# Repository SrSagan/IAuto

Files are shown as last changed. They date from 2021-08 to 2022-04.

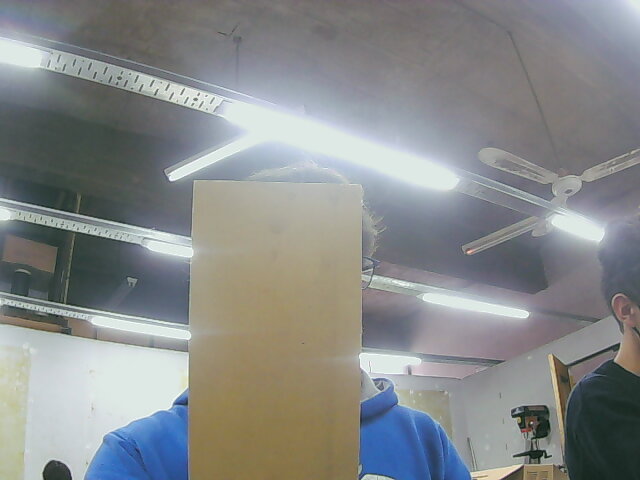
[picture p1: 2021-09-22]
camera/foto1.jpg

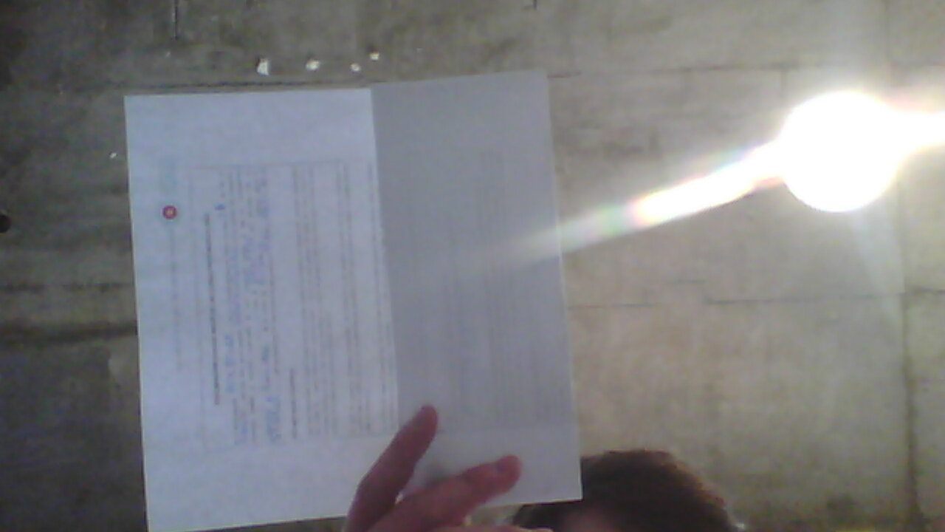
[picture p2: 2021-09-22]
camera/cuadrado.jpg

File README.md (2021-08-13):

# IAuto

IAuto is a little car that's controlled by an artificial intelligence, the brain of the operations is a Raspberry pi 3 that's controlling 2 DC motors and has a camera connected to it.

# Objectives

This project is merely for education, not only learn how to code advanced algorithms but also to use as an example for other poeple who might be trying to learn something similar.

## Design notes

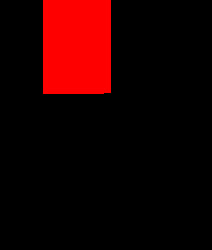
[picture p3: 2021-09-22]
camera/square.jpg

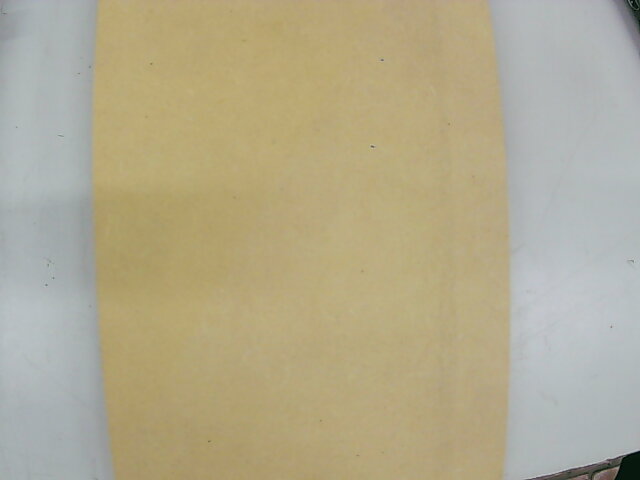
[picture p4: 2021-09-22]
camera/foto2.jpg

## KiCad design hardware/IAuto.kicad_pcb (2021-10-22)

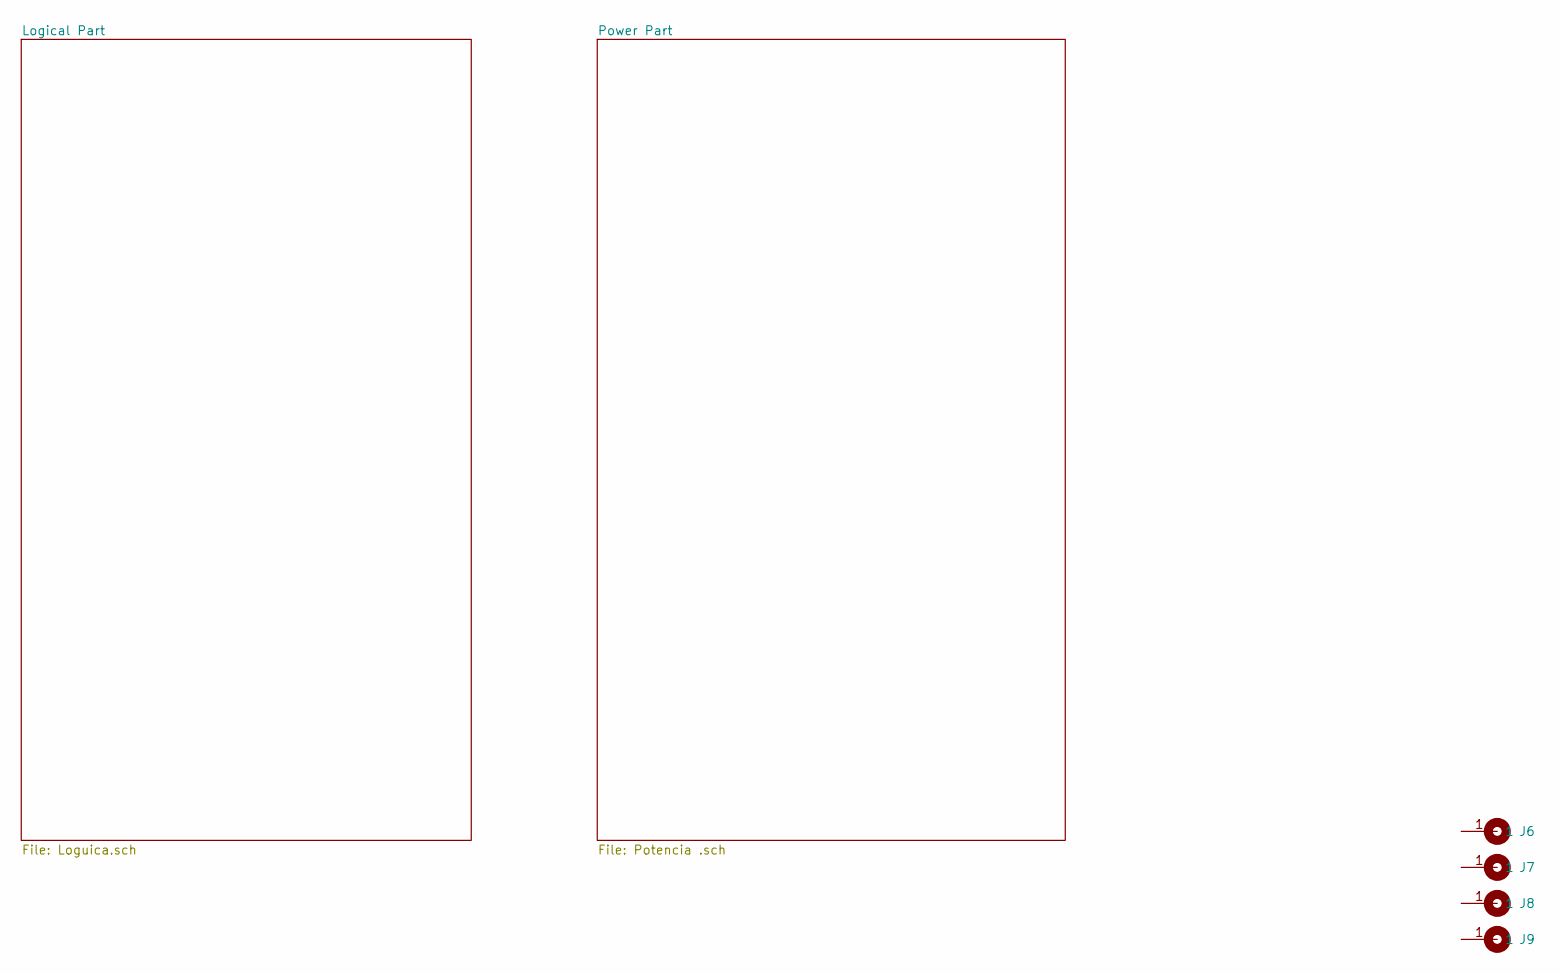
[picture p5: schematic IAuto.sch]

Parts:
J6, J7, J8, J9: Cable_PAD; Separador_M3_10mm

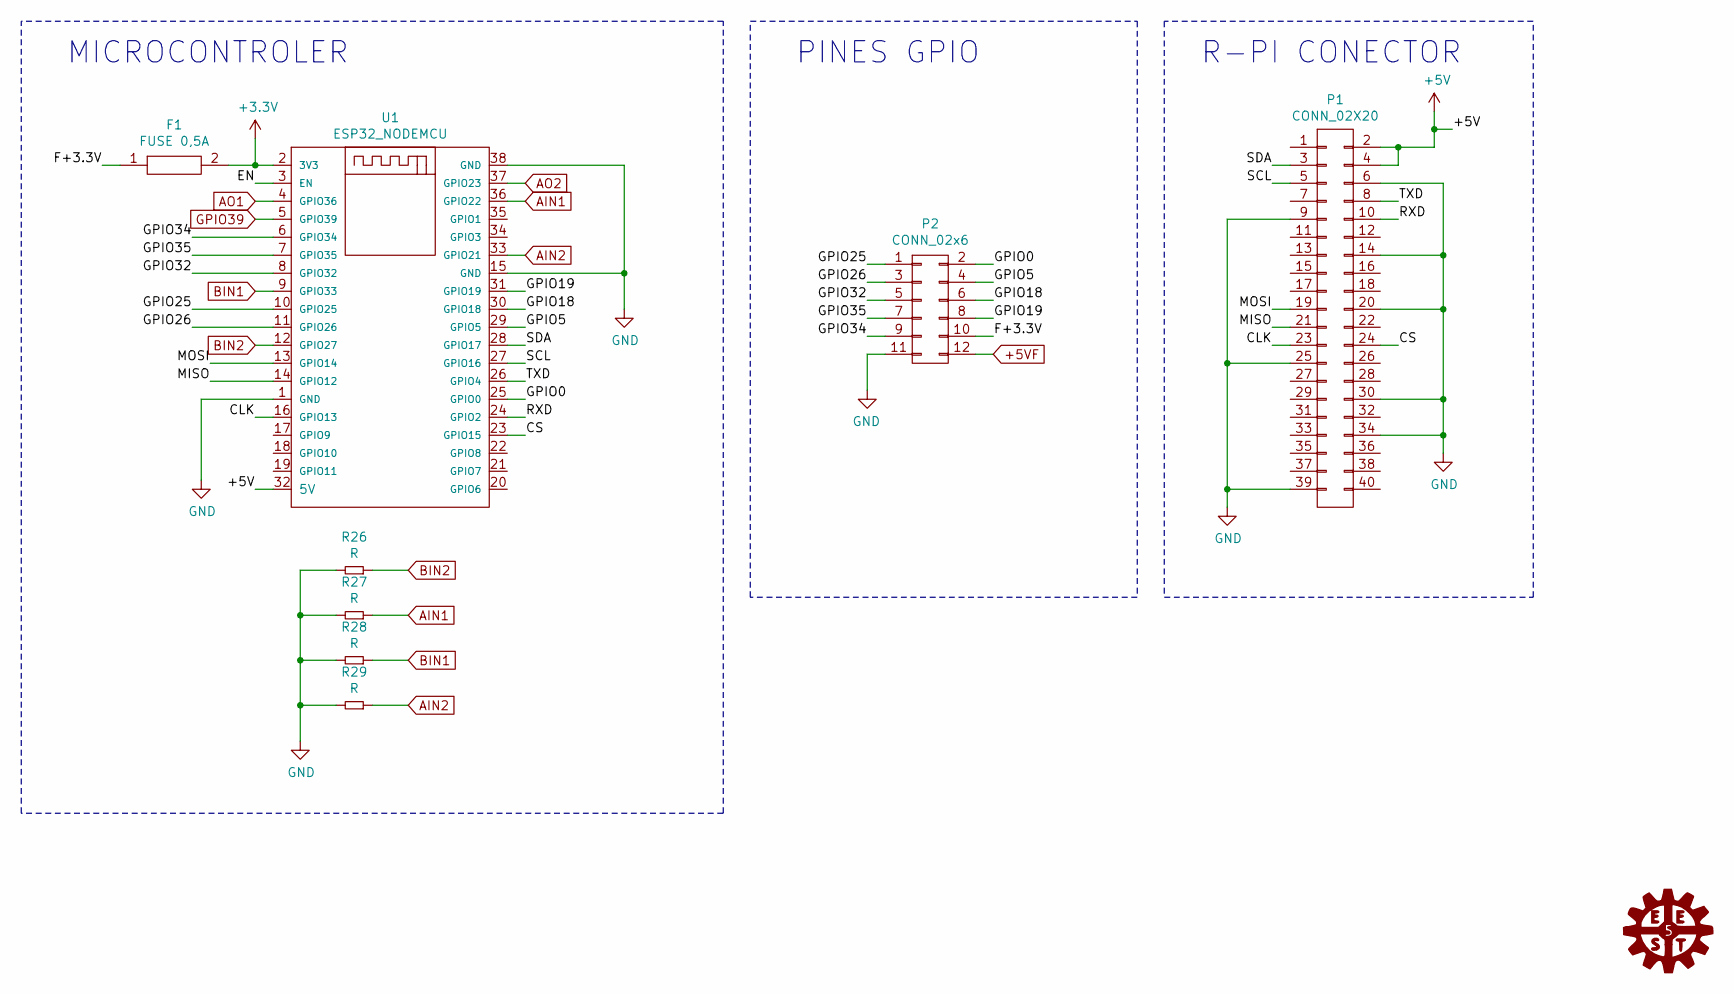
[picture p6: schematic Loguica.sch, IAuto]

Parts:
F1: FUSE 0,5A; R_1206
P1: CONN_02X20; Pin_Header_Straight_2x20
P2: CONN_02x6; Pin_strip_2x6
R26, R27, R28, R29: R; R_0805
U1: ESP32_NODEMCU; NodeMCU-ESP32

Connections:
+3V3: F1.2, U1.2 (3V3); also elsewhere on the board
+5V: P1.2, P1.4, U1.32 (5V); also elsewhere on the board
+5VF: P2.12; also elsewhere on the board
/Logical Part/CLK: P1.23, U1.16 (GPIO13)
/Logical Part/CS: P1.24, U1.23 (GPIO15)
/Logical Part/F+3.3V: F1.1, P2.10
/Logical Part/GPIO0: P2.2, U1.25 (GPIO0)
/Logical Part/GPIO5: P2.4, U1.29 (GPIO5)
/Logical Part/GPIO18: P2.6, U1.30 (GPIO18)
/Logical Part/GPIO19: P2.8, U1.31 (GPIO19)
/Logical Part/GPIO25: P2.1, U1.10 (GPIO25)
/Logical Part/GPIO26: P2.3, U1.11 (GPIO26)
/Logical Part/GPIO32: P2.5, U1.8 (GPIO32)
/Logical Part/GPIO34: P2.9, U1.6 (GPIO34)
/Logical Part/GPIO35: P2.7, U1.7 (GPIO35)
/Logical Part/MISO: P1.21, U1.14 (GPIO12)
/Logical Part/MOSI: P1.19, U1.13 (GPIO14)
/Logical Part/RXD: P1.10, U1.24 (GPIO2)
/Logical Part/SCL: P1.5, U1.27 (GPIO16)
/Logical Part/SDA: P1.3, U1.28 (GPIO17)
/Logical Part/TXD: P1.8, U1.26 (GPIO4)
AIN1: R27.1, U1.36 (GPIO22); also elsewhere on the board
AIN2: R29.1, U1.33 (GPIO21); also elsewhere on the board
AO1: U1.4 (GPIO36); also elsewhere on the board
AO2: U1.37 (GPIO23); also elsewhere on the board
BIN1: R28.1, U1.9 (GPIO33); also elsewhere on the board
BIN2: R26.1, U1.12 (GPIO27); also elsewhere on the board
GND: P1.6, P1.9, P1.14, P1.20, P1.25, P1.30, P1.34, P1.39, P2.11, R26.2, R27.2, R28.2, R29.2, U1.1 (GND), U1.15 (GND), U1.38 (GND); also elsewhere on the board
GPIO39: U1.5 (GPIO39); also elsewhere on the board

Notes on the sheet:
MICROCONTROLER
R-PI CONECTOR
PINES GPIO

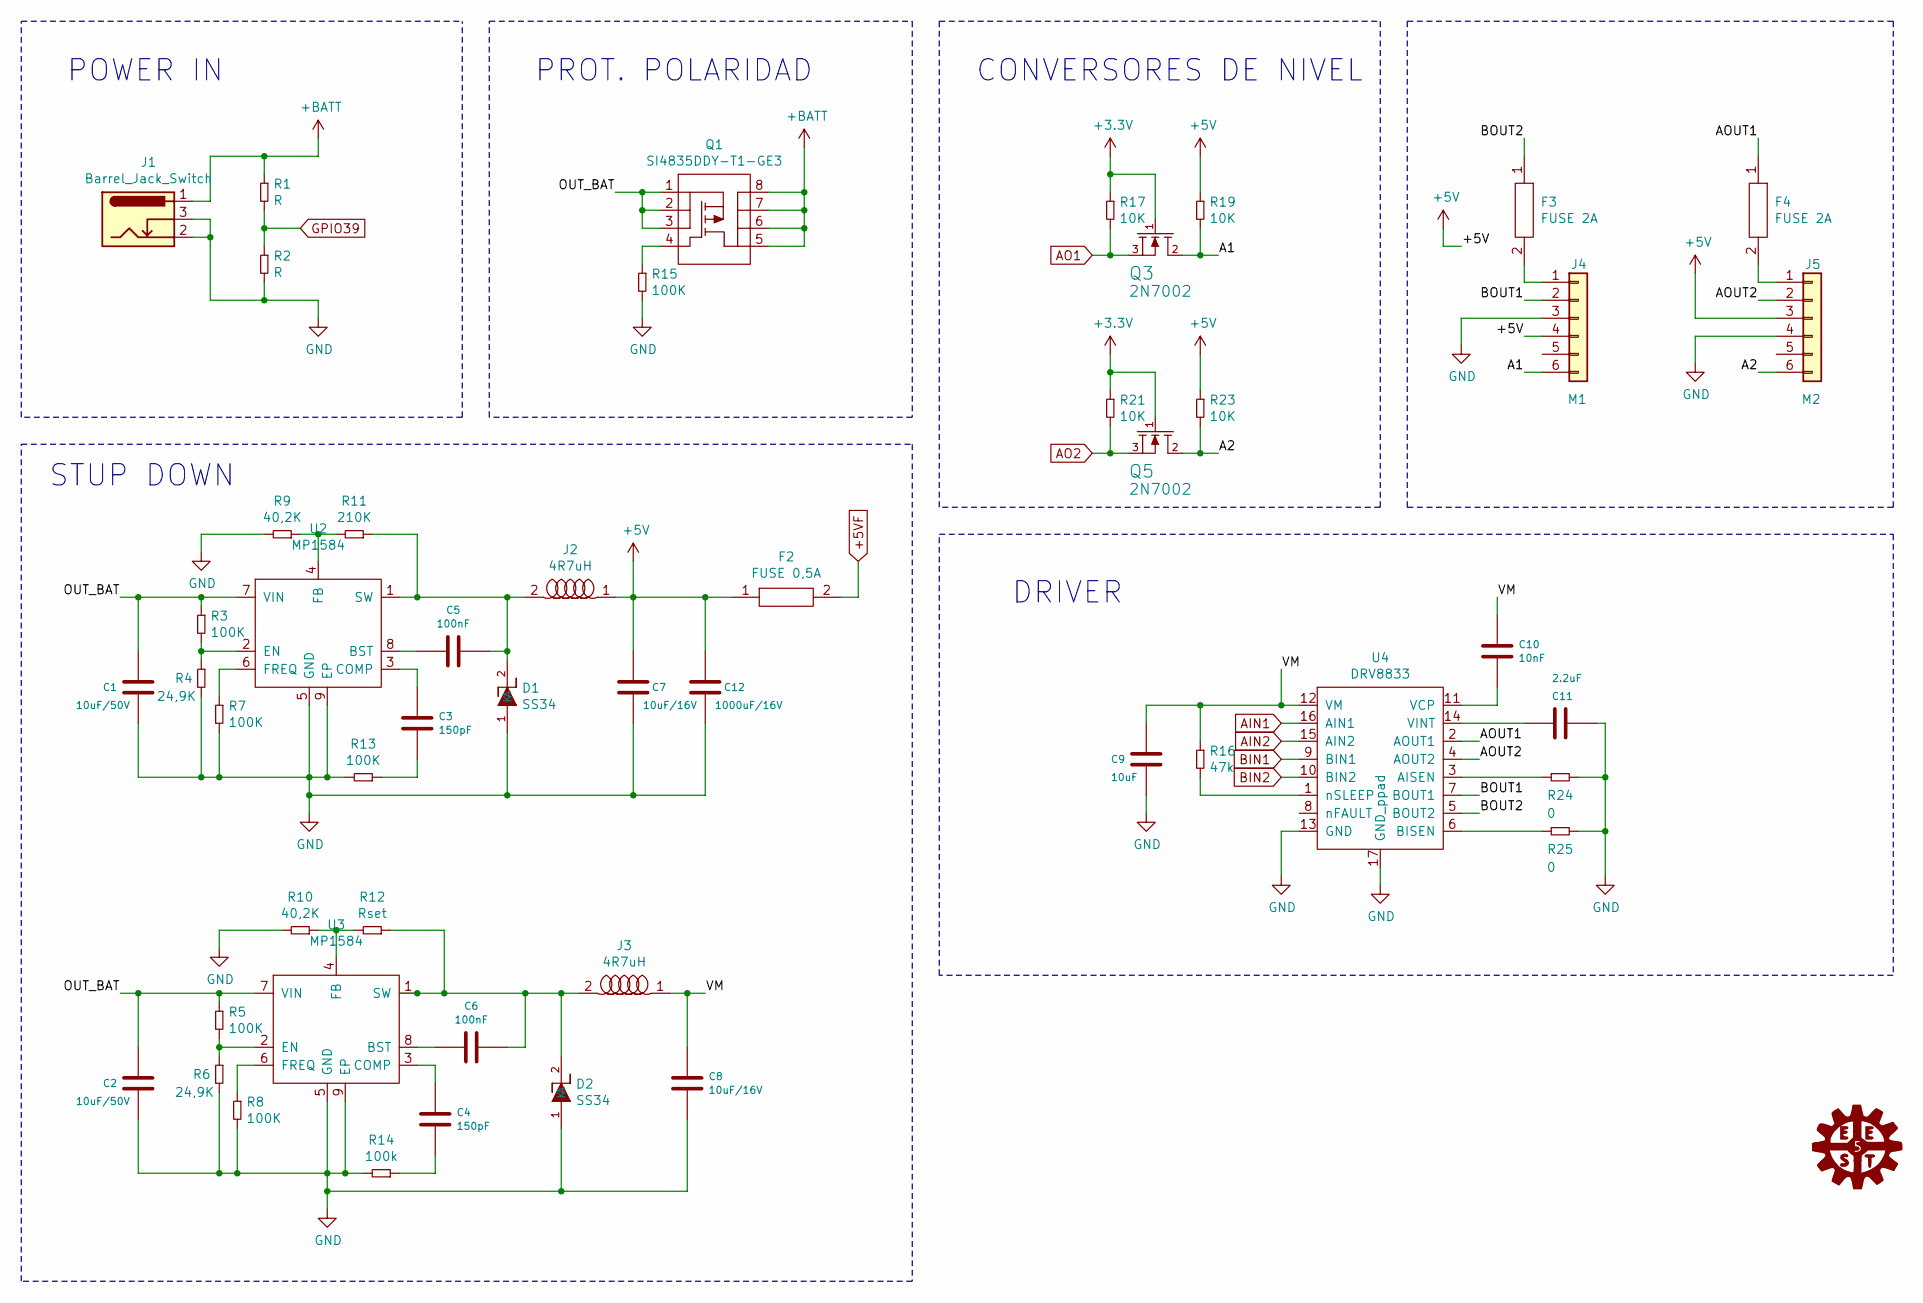
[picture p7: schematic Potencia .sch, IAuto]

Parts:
C1, C2: 10uF/50V; C_1206
C3, C4: 150pF; C_0805
C5, C6: 100nF; C_0805
C7, C8: 10uF/16V; C_1206
C9: 10uF; C_1206
C10: 10nF; C_0805
C11: 2.2uF; C_0805
C12: 1000uF/16V; CAP_ELEC_8x11.5mm
D1, D2: SS34; DO-214AB
F2: FUSE 0,5A; R_1206
F3, F4: FUSE 2A; FUSC5141X200N
J1: Barrel_Jack_Switch; Jack_hembra_DC_barrel
J2, J3: 4R7uH; SRP65404R7M
J4: M1; Conector_jst_6_pins_2mm
J5: M2; Conector_jst_6_pins_2mm
Q1: SI4835DDY-T1-GE3; SSOP-8
Q3, Q5: 2N7002; SOT23
R1, R2: R; R_0805
R3, R5, R7, R8, R13, R15: 100K; R_0805
R4, R6: 24,9K; R_0805
R9, R10: 40,2K; R_0805
R11: 210K; R_0805
R12: Rset; R_0805
R14: 100k; R_0805
R16: 47k; R_0805
R17, R19, R21, R23: 10K; R_0805
R24, R25: 0; R_0805
U2, U3: MP1584; SOIC8E
U4: DRV8833; HTSSOPP

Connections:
+3V3: Q3.1 (G), Q5.1 (G), R17.1, R21.1; also elsewhere on the board
+5V: C7.2, C12.1, F2.1, J2.1, J4.4, J5.3, R19.1, R23.1; also elsewhere on the board
+5VF: F2.2; also elsewhere on the board
+BATT: J1.1, Q1.5, Q1.6, Q1.7, Q1.8, R1.1
/Power Part/A1: J4.6, Q3.2 (D), R19.2
/Power Part/A2: J5.6, Q5.2 (D), R23.2
/Power Part/AOUT1: F4.1, U4.2 (AOUT1)
/Power Part/AOUT2: J5.2, U4.4 (AOUT2)
/Power Part/BOUT1: J4.2, U4.7 (BOUT1)
/Power Part/BOUT2: F3.1, U4.5 (BOUT2)
/Power Part/OUT_BAT: C1.2, C2.2, Q1.1, Q1.2, Q1.3, R3.1, R5.1, U2.7 (VIN), U3.7 (VIN)
/Power Part/VM: C8.2, C9.1, C10.1, J3.1, R16.1, U4.12 (VM)
AIN1: U4.16 (AIN1); also elsewhere on the board
AIN2: U4.15 (AIN2); also elsewhere on the board
AO1: Q3.3 (S), R17.2; also elsewhere on the board
AO2: Q5.3 (S), R21.2; also elsewhere on the board
BIN1: U4.9 (BIN1); also elsewhere on the board
BIN2: U4.10 (BIN2); also elsewhere on the board
GND: C1.1, C2.1, C7.1, C8.1, C9.2, C11.1, C12.2, D1.1 (A), D2.1 (A), J1.2, J1.3, J4.3, J5.4, R2.2, R4.2, R6.2, R7.2, R8.2, R9.2, R10.2, R13.2, R14.2, R15.2, R24.2, R25.2, U2.5 (GND), U2.9 (EP), U3.5 (GND), U3.9 (EP), U4.13 (GND), U4.17 (GND_ppad); also elsewhere on the board
GPIO39: R1.2, R2.1; also elsewhere on the board
unnamed: C3.1, R13.1
unnamed: C3.2, U2.3 (COMP)
unnamed: C4.1, R14.1
unnamed: C4.2, U3.3 (COMP)
unnamed: C5.1, U2.8 (BST)
unnamed: C5.2, D1.2 (K), J2.2, R11.1, U2.1 (SW)
unnamed: C6.1, U3.8 (BST)
unnamed: C6.2, D2.2 (K), J3.2, R12.1, U3.1 (SW)
unnamed: C10.2, U4.11 (VCP)
unnamed: C11.2, U4.14 (VINT)
unnamed: F3.2, J4.1
unnamed: F4.2, J5.1
unnamed: Q1.4, R15.1
unnamed: R3.2, R4.1, U2.2 (EN)
unnamed: R5.2, R6.1, U3.2 (EN)
unnamed: R7.1, U2.6 (FREQ)
unnamed: R8.1, U3.6 (FREQ)
unnamed: R10.1, R12.2, U3.4 (FB)
unnamed: R9.1, R11.2, U2.4 (FB)
unnamed: R16.2, U4.1 (nSLEEP)
unnamed: R24.1, U4.3 (AISEN)
unnamed: R25.1, U4.6 (BISEN)

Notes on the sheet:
POWER IN
CONVERSORES DE NIVEL
PROT. POLARIDAD
STUP DOWN
DRIVER

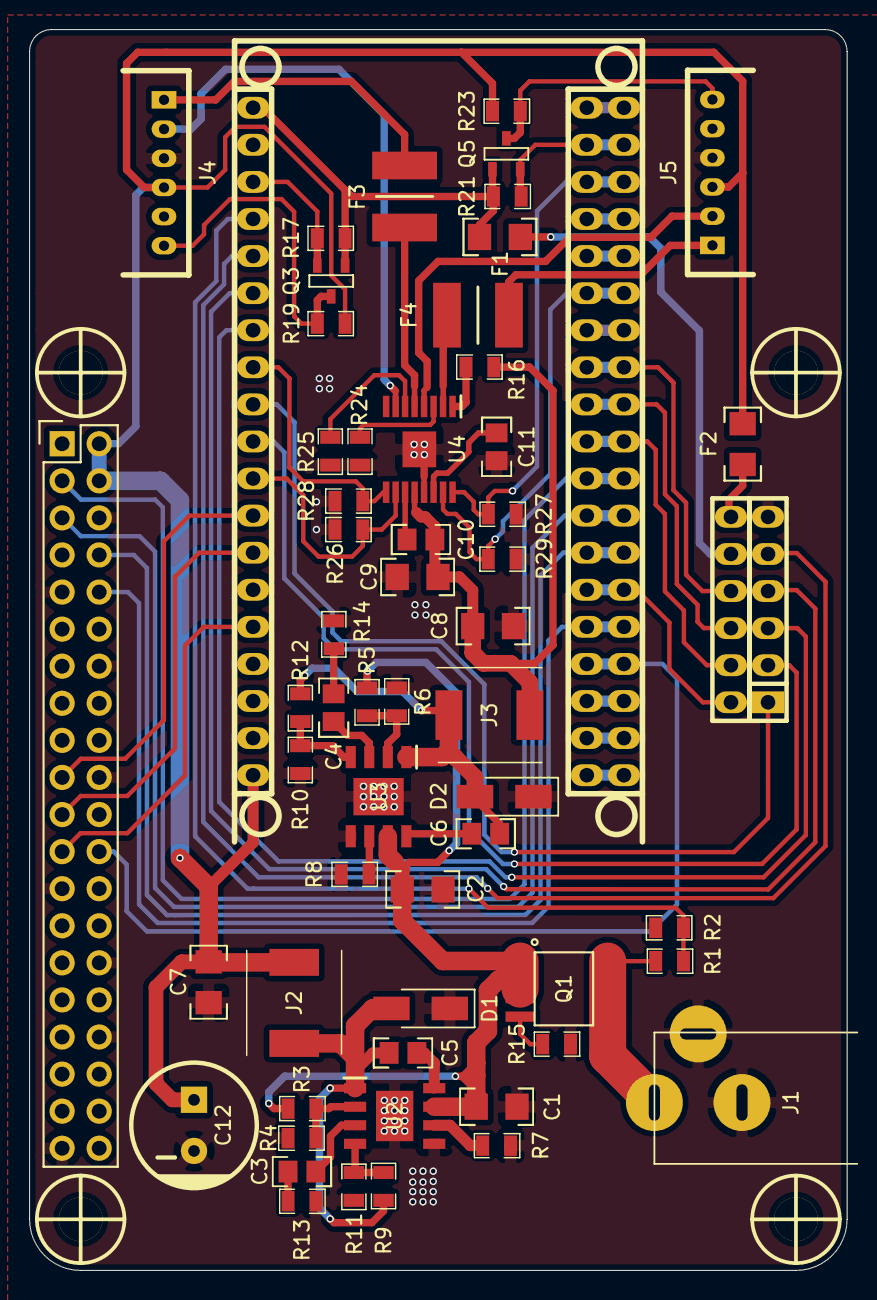
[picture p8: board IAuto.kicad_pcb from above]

Board: 2 copper layers, 56.0 x 85.0 mm, 62 parts (0 on the bottom side), 60 nets.

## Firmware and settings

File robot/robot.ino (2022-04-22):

#include <SoftwareSerial.h>

#include <Servo.h>

#include <EEPROM.h>

#include "RB_QMIND_PLUS.h"
//#include "RB_QMIND.h"

#define KP 7
#define KD 2000
#define KI 2
#define PERIODO 5
int valor = 0;
int valor_motor = 0;
RB_EncoderMotor  M1(1);
RB_EncoderMotor  M2(2);

int terminal(){
    uint8_t grados;
    static String dato;
    char caracter = NULL;
    if(Serial.available()){
        dato = "";
        while(Serial.available() > 0){
            caracter = (char)Serial.read();
            dato = dato + (String)caracter;
            if(caracter == "\n"){
              break;
            }
        }
    }
    grados = dato.toInt();
    return grados; 
}

int PID(int setpoint, int current_value){
  float error = setpoint - current_value;
  static float error_previous, PID_i;
  float PID_p, PID_d, PID_total;
  static unsigned long time;
  if(millis() > time + PERIODO){
    PID_p = KP * error;
    PID_d = KD * ((error - error_previous)/PERIODO);
    if(error < 20 && error > -20){
      PID_i += KI * error;
    }
    else{
      PID_i = 0;
    }
    PID_total = PID_p + PID_d + PID_i;
    error_previous = error;
    if(PID_total <= -500){
      PID_total = -500;
    }
    if(PID_total > 500){
      PID_total = 500;
    }
  }

  return map(PID_total, -500, 500, -100, 100);
}
void motor(int speet){
    if(speet < 0){
        M1.SetMotorPwm(speet * -1);
        M2.SetMotorPwm(0);
    }
    else{
        M1.SetMotorPwm(0);
        M2.SetMotorPwm(speet);
    }
    
}
void setup() {
  Serial.begin(115200);
  M1.SetMotionMode(0);
  M2.SetMotionMode(0);
  pinMode(20,OUTPUT);
  digitalWrite(20,HIGH);
  delay(500);

  delay(int(1 * 1000));
  M1.SetMotionMode(0);
  M2.SetMotionMode(0);
  pinMode(20,OUTPUT);
  digitalWrite(20,HIGH);
}

void loop() {
  valor = terminal();
  valor_motor = PID(0 , valor);
  motor(valor_motor);
}

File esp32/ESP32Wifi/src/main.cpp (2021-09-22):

#include <Arduino.h>
#include <Arduino.h>
#include <WiFi.h>
#define INT1 27
#define INT2 5
#define INT3 18
#define INT4 19
#define INT1_CHANNEL 0
#define INT2_CHANNEL 1
#define INT3_CHANNEL 2
#define INT4_CHANNEL 3
#define RESOLUTION 10
#define FREQUENCY 30000
#define VAL 900
#define VAL2 0
#define ENABLE 0

//------------------Servidor Web en puerto 80---------------------

WiFiServer server(80);

//---------------------Credenciales de WiFi-----------------------

const char* ssid     = "Telecentro-1308";
const char* password = "NTZ2MGZKZJN2";

//---------------------VARIABLES GLOBALES-------------------------
byte contconexion = 0;
byte moving = 0;
String header; // Variable para guardar el HTTP request

//------------------------CODIGO HTML-----------------------------

String pagina = "<!DOCTYPE html>"
"<html>"
"<head>"
"<meta charset='utf-8' />"
"<title>Servidor Web ESP32</title>"
"</head>"
"<body>"
"<center>"
"<h1>Servidor Web ESP32</h1>"
"<p><a href='/forward'><button style='height:200px;width:100px'>FORWARD</button></a></p>"
"<p><a href='/left'><button style='height:100px;width:200px'>LEFT</button></a>"
"<a href='/stop'><button style='height:100px;width:100px'>STOP</button></a>"
"<a href='/right'><button style='height:100px;width:200px'>RIGHT</button></a></p>"
"<p><a href='/reverse'><button style='height:200px;width:100px'>REVERSE</button></a></p>"
"</center>"
"</body>"
"</html>";

//-------------------------FUNCIONES------------------------------

byte wifiControl(){
  static byte direction;
  WiFiClient client = server.available();   // Escucha a los clientes entrantes

  if (client) {                             // Si se conecta un nuevo cliente
    Serial.println("New Client.");          // 
    String currentLine = "";                //
    while (client.connected()) {            // loop mientras el cliente está conectado
      if (client.available()) {             // si hay bytes para leer desde el cliente
        char c = client.read();             // lee un byte
        Serial.write(c);                    // imprime ese byte en el monitor serial
        header += c;
        if (c == '\n') {                    // si el byte es un caracter de salto de linea
          // si la nueva linea está en blanco significa que es el fin del 
          // HTTP request del cliente, entonces respondemos:
          if (currentLine.length() == 0) {
            client.println("HTTP/1.1 200 OK");
            client.println("Content-type:text/html");
            client.println("Connection: close");
            client.println();
            
            // establese la dirección del auto
            if (header.indexOf("GET /forward") >= 0) {
              direction = 0;
            } 
            else if (header.indexOf("GET /reverse") >= 0) {
              direction = 1;
            } 
            else if (header.indexOf("GET /left") >= 0) {
              direction = 2;
            }
            else if (header.indexOf("GET /right") >= 0) {
              direction = 3;
            }
            else if (header.indexOf("GET /stop") >= 0) {
              direction = 4;
            }
            
            // Muestra la página web
            client.println(pagina);
            
            // la respuesta HTTP termina con una linea en blanco
            client.println();
            break;
          } else { // si tenemos una nueva linea limpiamos currentLine
            currentLine = "";
          }
        } else if (c != '\r') {  // si C es distinto al caracter de retorno de carro
          currentLine += c;      // lo agrega al final de currentLine
        }
      }
    }
    // Limpiamos la variable header
    header = "";
    // Cerramos la conexión
    client.stop();
//    Serial.println("Client disconnected.");
//    Serial.println("");
  }
  return direction;
}
void driverMotor(int valor){ //setea el valor de los motores segun el valor que recibe 
  if(valor == 0){
    ledcWrite(INT1_CHANNEL, VAL);
    ledcWrite(INT2_CHANNEL, VAL2);
    ledcWrite(INT3_CHANNEL, VAL);
    ledcWrite(INT4_CHANNEL, VAL2);
     if(ENABLE){
      Serial.println(valor); //imprime el valor de la variable
      Serial.println(digitalRead(INT1), digitalRead(INT2));//imprime el estado de los motores
      Serial.println(digitalRead(INT3), digitalRead(INT4));// solo funciona si el valor es mayor que el umbral 
    }
  }
  else if (valor == 1){
    ledcWrite(INT3_CHANNEL, VAL2);
    ledcWrite(INT2_CHANNEL, VAL);
    ledcWrite(INT1_CHANNEL, VAL2);
    ledcWrite(INT4_CHANNEL, VAL);
    if(ENABLE){
      Serial.println(valor);
      Serial.println(digitalRead(INT1), digitalRead(INT2));
      Serial.println(digitalRead(INT3), digitalRead(INT4));
    }
  }
  else if (valor == 2){
    ledcWrite(INT3_CHANNEL, VAL);
    ledcWrite(INT1_CHANNEL, VAL2);
    ledcWrite(INT2_CHANNEL, VAL2);
    ledcWrite(INT4_CHANNEL, VAL2);
    if(ENABLE){
      Serial.println(valor);
      Serial.println(digitalRead(INT1), digitalRead(INT2));
      Serial.println(digitalRead(INT3), digitalRead(INT4));
    }
  }
  else if (valor == 3){
    ledcWrite(INT2_CHANNEL, VAL2);
    ledcWrite(INT4_CHANNEL, VAL2);
    ledcWrite(INT1_CHANNEL, VAL);
    ledcWrite(INT3_CHANNEL , VAL2);
    if(ENABLE){
      Serial.println(valor);
      Serial.println(digitalRead(INT1), digitalRead(INT2));
      Serial.println(digitalRead(INT3), digitalRead(INT4));
    }
  }
    else if (valor == 4){
    ledcWrite(INT2_CHANNEL, VAL2);
    ledcWrite(INT4_CHANNEL, VAL2);
    ledcWrite(INT1_CHANNEL, VAL2);
    ledcWrite(INT3_CHANNEL , VAL2);
    if(ENABLE){
      Serial.println(valor);
      Serial.println(digitalRead(INT1), digitalRead(INT2));
      Serial.println(digitalRead(INT3), digitalRead(INT4));
    }
  }
}

//---------------------------SETUP--------------------------------
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
